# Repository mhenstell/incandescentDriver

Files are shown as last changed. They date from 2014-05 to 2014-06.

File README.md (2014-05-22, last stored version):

## Chandelier project

Four rings:
* 13 Elements
* 10 Elements
* 8 Elements
* 6 Elements
* Hanging bulb

Number of bulbs: (13 + 10 + 8 + 6) * 4 = 148 E12 globes ([PLT 219E24V5W](http://www.1000bulbs.com/product/61895/DEC-100150.html))

Number of bases: 148 E12 sockets ([SOCK-901556](http://www.1000bulbs.com/product/62223/SOCK-901556.html?ref=none))

Number of PCBs: (13 + 10 + 8 + 6) / 2 = 19 PCBs

Ring 1 (Outer) - 52 bulbs, 260 watts (11 amps)
Ring 2 - 40 bulbs, 200 watts (8.3 amps)
Ring 3 - 32 bulbs, 160 watts (7 amps)
Ring 4 (Inner) - 24 bulbs, 120 watts (5 amps)

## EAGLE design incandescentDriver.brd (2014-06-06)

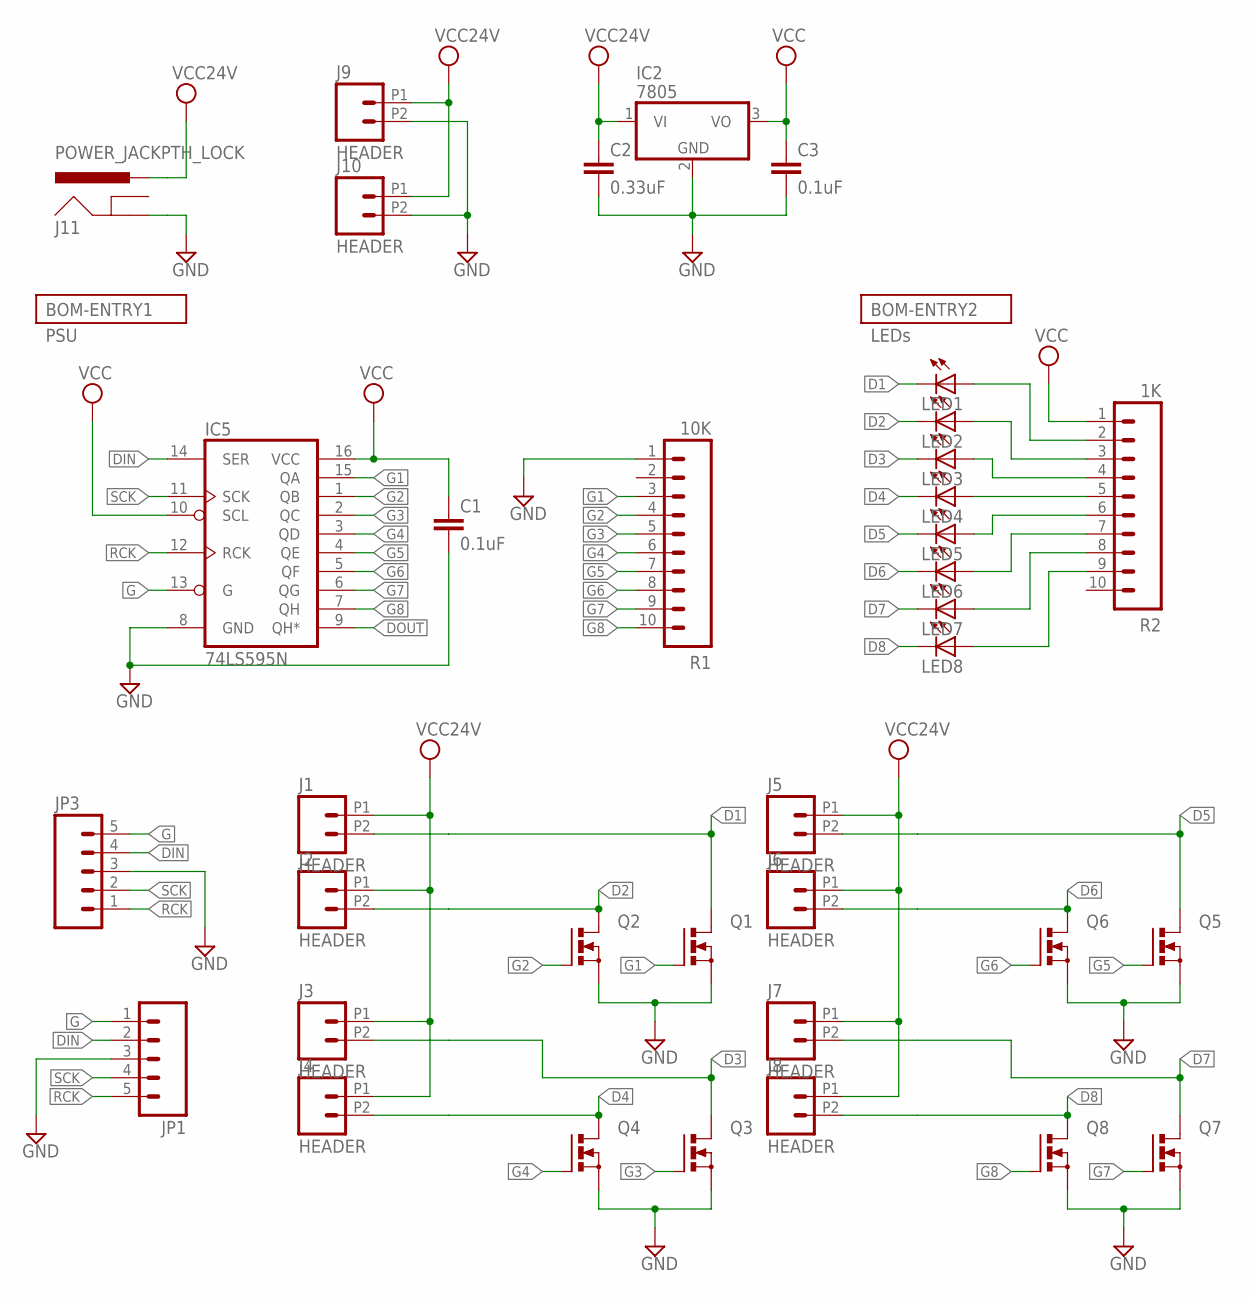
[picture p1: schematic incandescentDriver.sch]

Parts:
C1, C3: 0.1uF; CAP-PTH-SMALL; PARTNO SR295E104MAR
C2: 0.33uF; CAP-PTH-SMALL; PARTNO FK24X7R1H334K
IC2: 7805; TO220V; PARTNO NCP7805TG
IC5: 74LS595N; DIL16; PARTNO SN74HC164N
J1, J2, J3, J4, J5, J6, J7, J8, J9, J10: HEADER; 1X02-5.08-SCREWTERM; PARTNO OSTTC022162
J11: POWER_JACKPTH_LOCK; POWER_JACK_PTH_LOCK; PARTNO PJ-202A
JP1, JP3: M05LOCK; 1X05_LOCK; PARTNO M20-9960545
LED1, LED2, LED3, LED4, LED5, LED6, LED7, LED8: LED5MM
Q1, Q2, Q3, Q4, Q5, Q6, Q7, Q8: PMOSFET_NTO220BV; TO220BV; PARTNO FQP13N10L
R1: 10K; 1X10_LOCK; PARTNO L101S103LF
R2: 1K; 1X10_LOCK; PARTNO 4609X-101-102LF

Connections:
D1: J1.P2 (1), LED1.K (C), Q1.D
D2: J2.P2 (1), LED2.K (C), Q2.D
D3: J3.P2 (1), LED3.K (C), Q3.D
D4: J4.P2 (1), LED4.K (C), Q4.D
D5: J5.P2 (1), LED5.K (C), Q5.D
D6: J6.P2 (1), LED6.K (C), Q6.D
D7: J7.P2 (1), LED7.K (C), Q7.D
D8: J8.P2 (1), LED8.K (C), Q8.D
DIN: IC5.14 (SER), JP1.2, JP3.4
DOUT: IC5.9 (QH*)
G: IC5.13 (G), JP1.1, JP3.5
G1: IC5.15 (QA), Q1.G, R1.3
G2: IC5.1 (QB), Q2.G, R1.4
G3: IC5.2 (QC), Q3.G, R1.5
G4: IC5.3 (QD), Q4.G, R1.6
G5: IC5.4 (QE), Q5.G, R1.7
G6: IC5.5 (QF), Q6.G, R1.8
G7: IC5.6 (QG), Q7.G, R1.9
G8: IC5.7 (QH), Q8.G, R1.10
GND: C1.2, C2.2, C3.2, IC2.2 (GND), IC5.8 (GND), J9.P2 (1), J10.P2 (1), J11.GND, JP1.3, JP3.3, Q1.S, Q2.S, Q3.S, Q4.S, Q5.S, Q6.S, Q7.S, Q8.S, R1.1
unnamed: LED1.A, R2.2
unnamed: LED2.A, R2.3
unnamed: LED3.A, R2.4
unnamed: LED4.A, R2.5
unnamed: LED5.A, R2.6
unnamed: LED6.A, R2.7
unnamed: LED7.A, R2.8
unnamed: LED8.A, R2.9
RCK: IC5.12 (RCK), JP1.5, JP3.1
SCK: IC5.11 (SCK), JP1.4, JP3.2
VCC: C1.1, C3.1, IC2.3 (VO), IC5.10 (SCL), IC5.16 (VCC), R2.1
VCC24V: C2.1, IC2.1 (VI), J1.P1 (2), J2.P1 (2), J3.P1 (2), J4.P1 (2), J5.P1 (2), J6.P1 (2), J7.P1 (2), J8.P1 (2), J9.P1 (2), J10.P1 (2), J11.PWR

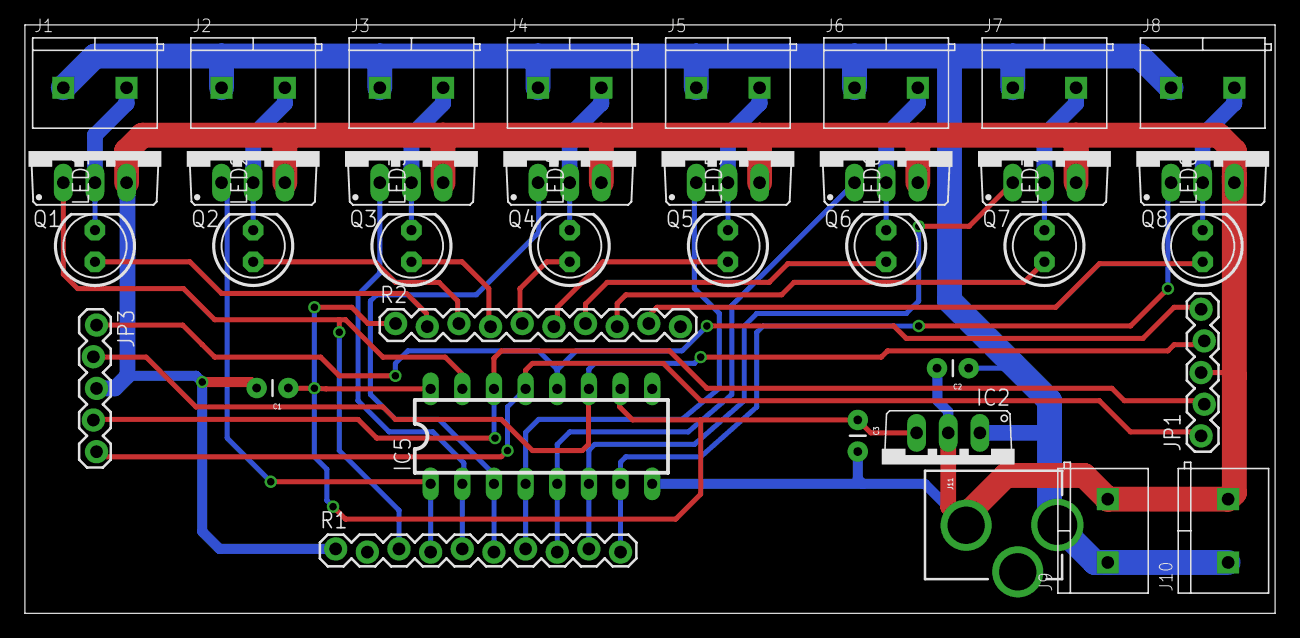
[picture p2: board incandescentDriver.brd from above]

Board: 2 copper layers, 100.3 x 47.2 mm, 36 parts (0 on the bottom side), 31 nets.

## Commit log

2014-04-15 adding mosfet driver
    [chandelier.brd, chandelier.sch]
2014-04-29 adding uncommitted things
    [chandelier.brd, chandelier.sch, mechanismTest.scad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]
2014-05-08 added bom
    [chandelier.brd, chandelier.sch]
2014-05-09 added num of elements
    [chandelierTest.scad]
2014-05-11 adding dxfs
    [woodx4-2.dxf, woodx4-3.dxf, woodx4.dxf]
2014-05-11 added radii
    [chandelierTest.scad]
2014-05-12 wood and braces
    [brace-x6.stl, braces-1.stl, braces-R2-R3.stl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]
2014-05-19 added small braces
    [chandelierBraces.scad]
2014-05-19 added center bulb
    [brace-R4.stl]
2014-05-19 adding arduino firmware and python host
2014-05-22 updated board to fix footprint issue
    [chandelier.brd, chandelier.sch]
2014-05-22 fixed braces angles? and put all in one file
    [braces-all.stl, chandelierBraces.scad]
2014-05-30 fixed trace issues for 1.3
    [chandelier.brd, chandelier.sch]
2014-06-06 adding new incandescent board
    [incandescentDriver.brd, incandescentDriver.sch]
2014-06-06 working on BOM
    [incandescentDriver.brd, incandescentDriver.sch]
2014-06-23 cleaning up older chandelier stuff
    [brace-R4.stl, brace-x6.stl, braces-1.stl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]

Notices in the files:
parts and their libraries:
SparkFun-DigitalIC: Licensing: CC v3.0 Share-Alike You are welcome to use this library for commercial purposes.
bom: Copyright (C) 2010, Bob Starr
